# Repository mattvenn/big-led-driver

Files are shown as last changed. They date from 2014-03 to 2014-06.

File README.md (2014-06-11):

# Big 7 segment display boards

PCBs and Python driver for Raspberry Pi.

Uses the [TLC5916](http://www.ti.com/product/tlc5916), a constant current, 8 bit driver, designed for daisy chaining.

Check the video of it [in action on youtube](http://youtu.be/0-mJzARANds)

# PCB

Available from £6.50 from [me](http://www.mattvenn.net/2014/02/25/big-7-segment-display-pcb/).

Also available at a higher price from [OSH park](http://oshpark.com/shared_projects/hZyNfTTa), hopefully will find a way to make them cheaper soon!

# Python Example

    import driver
    driver.update("0.35") #requires 3 panels

# Electronics

*Important* Please read and understand the power supply pins below before connecting your board to a controller.

## Pins

1. Ground (0v).
2. Ground (0v).
3. +5v - The supply for the driver chip. This can be from 3.3v to 5v. It should be the same level as the logic levels of your controller. So for a Raspberry Pi which operates at 3.3v it should be connected to 3.3v.
4. +12v - The supply for the LEDs. Maximum 20V. Current is set with R1 (see notes below)
5. SDI/SDO - Serial Data In on the left of the board and Out on the right of the board (for chaining)
6. CLK - Clock. Next bit gets shifted when clock goes high.
7. LE - Latch Enable - the shift register is latched to the output when this is transitions from high to low.
8. !OE - Not Output Enable. Pulled up to the logic supply by a 500k resistor  in the chip. Pull low to turn on the LEDs. Useful for PWM control of brightness.

## LED arrangement

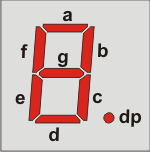
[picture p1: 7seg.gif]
Segments


* A is bit 0 (gets clocked in first)
* G is bit 6
* Decimal point is bit 7 (gets clocked in last)

So `[ 1,1,1,1,1,1,0,0 ]` would be 0 with no decimal point.

## The driver chip: TLC5916

[Datasheet](http://www.ti.com/lit/ds/symlink/tlc5916.pdf) Overview

* 3.3v to 5v supply
* up to 120mA per channel
* Max LED voltage 20v

## Required Components - BOM

The long digit in the following list are Farnell order numbers

* R1: 2329486, 1, RESISTOR CARBON  1K0 0.25W 
* C5: 2112910, 1, CAP CER Y5V 1UF 50V RAD 
* C4: 1870987, 1, CAP ALU ELEC 22UF 6.3V RAD 
* C2: 1871001, 1, CAP ALU ELEC 220UF 16V RAD 
* IC1: 1647814, 1, IC LED DRIVER 8CH PDIP16

And 22 10mm LEDs of your choice.

## Optional Components

* 1101347, 1, SOCKET IC DIL 0.3" 16WAY 
* 1097954, 1, HEADER PIN TIN 36WAY 1ROW 

## Notes

1. R1 sets the LED current. 1k works well at 12v supply. The lower the value the higher the current provided to the leds. See page 18 of the [Datasheet](http://www.ti.com/lit/ds/symlink/tlc5916.pdf) 
2. For cost reasons, the caps in the above list are sold in 10s only.
3. For cost reasons, the header above will do 4 boards with a few left over.

## Characteristics

* with LEDs from [oomlout](http://oomlout.com) and a 1k current resistor, average current while counting is 120mA, all segments on is 200mA.
* current sourced from !OE is 22uA.
* current drawn by 5v line (logic supply) is 10mA.

# License

This hardware is licensed under the [CERN open hardware license 1.2](http://www.ohwr.org/attachments/2388/cern_ohl_v_1_2.txt), which also included in this repository.

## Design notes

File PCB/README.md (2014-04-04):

# Physical specs

* outside dimension 120x83mm
* segment dimension 110x70mm

# Changes from V1

* moved bottom right mount hole for better spacing on the decimal point
* removed extra 12v cap
* reduced size of 200uf 5v cap to 20uf
* aligned in/out headers
* filleted corners of pcb
* fixed project links on top and bottom silk screen 
* moved components around to make it easier to 3d print a segmenter

# Todo for V1.1

* reduce DPI of OH logo to 300 as per advice from oshpark.
* change silkscreen for R1 resistance?
* change 5v silkscreen to 'logic supply'?

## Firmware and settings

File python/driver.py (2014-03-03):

"""
title: big 7 segment driver
author: matt venn, 2014
license: GPL attribution share alike
"""
import time

#undefine for testing with GPIO lib
raspi = True

#define which segments are on/off for each digit
#last element is for the point
letters = {
 '0' : [ 1,1,1,1,1,1,0,0 ], # 0
 '1' : [ 0,1,1,0,0,0,0,0 ], # 1
 '2' : [ 1,1,0,1,1,0,1,0 ], # 2
 '3' : [ 1,1,1,1,0,0,1,0 ], # 3
 '4' : [ 0,1,1,0,0,1,1,0 ], # 4
 '5' : [ 1,0,1,1,0,1,1,0 ], # 5
 '6' : [ 0,0,1,1,1,1,1,0 ], # 6
 '7' : [ 1,1,1,0,0,0,0,0 ], # 7
 '8' : [ 1,1,1,1,1,1,1,0 ], # 8
 '9' : [ 1,1,1,0,0,1,1,0 ], # 9
 ' ' : [ 0,0,0,0,0,0,0,0 ], 
 '.' : [ 0,0,0,0,0,0,0,1 ], 
 'P' : [ 1,1,0,0,1,1,1,1 ], 
}

if raspi:
    import RPi.GPIO as GPIO
    GPIO.setwarnings(False)
    GPIO.setmode(GPIO.BOARD)

    #pin defs
    not_oe = 8 #output enable
    le = 10 #latch
    clk = 12 #clock
    sdo = 16 #data out

    GPIO.setup(not_oe, GPIO.OUT)
    GPIO.setup(le, GPIO.OUT)
    GPIO.setup(clk, GPIO.OUT)
    GPIO.setup(sdo, GPIO.OUT)

    #turn off leds
    GPIO.output(not_oe, True)
    #turn off latch
    GPIO.output(le,False)
    #clock starts low
    GPIO.output(clk,False)

class driver:
    BLANK = 10
    def __init__(self):
        #verbose output
        self.verbose = True

        freq = 200 #hz
        self.pwm = GPIO.PWM(not_oe, freq)
        #lights off to start with
        self.pwm.start(100) #duty cycle

    #sends a string representation of a float, deals with floating points
    def update(self,number):
        point = False
        
        #send least significant digit first
        for char in reversed(number):
            if char == '.':
                point = True
                continue
            self.send_digit(char,point)
            point = False

        #latch the outputs
        if raspi:
            GPIO.output(le,True)
            GPIO.output(le,False)
        

    #send a char, with optional point
    def send_digit(self,char,point=False):
        #set the point bit
        if point:
            letters[char][7] = 1
        else:
            letters[char][7] = 0

        if self.verbose:
            print("sending %s%s = %s" % (
                char,
                '.' if point else '',
                ','.join(str(x) for x in letters[char]))
                )

        #8 clock pulses
        if raspi:
            for i in range(8):
                GPIO.output(clk,False)
                #data
                if letters[char][7-i]:
                    GPIO.output(sdo,True)
                else:
                    GPIO.output(sdo,False)

                GPIO.output(clk,True)

    #turn off leds
    def turn_off(self):
        if raspi:
            self.set_pwm(0)

    #turn on leds
    def turn_on(self):
        if raspi:
            self.set_pwm(100)


    def set_pwm(self,pwm):
        self.pwm.ChangeDutyCycle(100-pwm)

    def fade(self,start,end,length):
        if start > end:
           step = -1
        else:
            step = 1
        for i in range(start,end + step,step):
            time.sleep(float(length) / abs(start-end))
            self.set_pwm(i)

    def cleanup(self):
        self.set_pwm(0)
        GPIO.cleanup()
        #cleanup


#run a test sequence
if __name__ == '__main__':
    driver = driver()
    driver.set_pwm(100)
    print("running test sequence")
    point = False
    while True:
        for i in range(1000):
            string = "%.2f" % (i/100.0)
            print("sending %s" % string)
            driver.update(string)
            time.sleep(0.05)

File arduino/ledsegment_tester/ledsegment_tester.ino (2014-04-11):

#define NOE 9 //pwm
#define LE 8 //latch
#define CLK 10 //clock
#define SDO 11 //serial data
#define LED 13 //indicator led on arduino

byte segments[] = 
  {  
    0b11111100, //0
    0b01100000, //1
    0b11011010, //2
    0b11110010, //3
    0b01100110, //4
    0b10110110, //5
    0b00111110, //6
    0b11100000, //7
    0b11111110, //8
    0b11100110, //9
    0b00000001, //dot
  };
  
int seq_length;

//pwm settings  
int max_pwm = 255;
int min_pwm = 0;
int pwm_step = 10;
int fade_time = 5;



void setup()
{
  seq_length = sizeof(segments);
  Serial.begin(9600);
  Serial.println(seq_length);
  pinMode(LED,OUTPUT);
  pinMode(LE,OUTPUT);
  analogWrite(NOE,min_pwm);
  pinMode(CLK,OUTPUT);
  pinMode(SDO,OUTPUT);

  digitalWrite(LE,false);

}

void loop()
{
  for(int seq = 0; seq < seq_length; seq ++ )
  {
    digitalWrite(LED,true);
    
    //send the current segments
    for(int seg=0; seg< 8; seg ++)
    { 
      digitalWrite(CLK,false);
      delay(1);
      digitalWrite(SDO,segments[seq] & 1 << seg);
      digitalWrite(CLK,true);
      delay(1);
    }
    //fade in
    for(int p=min_pwm; p<max_pwm ; p+=pwm_step)
    {
      delay(fade_time);
      analogWrite(NOE,p);
      Serial.println(p);
    }

    //latch the shift register
    digitalWrite(LE,false);
    digitalWrite(LE,true);
    digitalWrite(LE,false);

    digitalWrite(LED,false);
    
    //wait till next sequence
    delay(100);

    //fade out
    for(int p=max_pwm; p>=min_pwm ; p-=pwm_step)
    {
      delay(fade_time);
      analogWrite(NOE,p);

    }
  }
}

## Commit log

2014-02-17 think its working, needs more leds
2014-02-19 leave leds on during update
2014-02-22 add scrolling, fix pwm bug
    [driver.py]
2014-02-27 switched to char instead of digit, took out scrolling
2014-03-03 added pcb and readme
    [7 segment driver.brd, 7 segment driver.sch]
2014-04-04 updated pcb
    [7 segment driver.brd, 7 segment driver.sch]
2014-04-11 arduino tester
2014-04-11 moved python driver to own dir
